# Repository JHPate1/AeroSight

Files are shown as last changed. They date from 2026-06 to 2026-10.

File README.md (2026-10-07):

# AeroSight
### An Open-Source, Low-Cost Retroreflective Schlieren Imaging System

## Overview
AeroSight is a high-fidelity Schlieren imaging device built to make advanced aerodynamic and thermodynamic visualization actually accessible. Professional-grade Schlieren setups, the kind NASA uses easily runs past $5,000. AeroSight delivers 1080p visualization for a fraction of that, using a modular optical design and open-source hardware. Swap lenses, swap beam splitters, tweak the software. The whole thing is built for people who want to experiment like real lab equipment.
Diagram
## How it looks inside
(Lost Media)
Guide:
Yellow-Enclosure
Blue-Lens Holder
Grey-Cam Holder
Orange-LED Holder
Red-BeamSplitter
## Why AeroSight?
* **Cheap where it counts:** Total build cost is about $514.
* **Modular:** Upgrade optics (lens, NPBS cube) as your needs change.
* **Flexible software:** Raw video, real-color rendering, custom gradient mapping, all the good stuff.

## Project Contents
```/PCB/``` PCB files
```3D ``` 3D Printed Files

## Bill of Materials (BOM)

| Category | Item | Quantity | Total |
| :--- | :--- | :--- | :--- |
| **Processing** | Waveshare ESP32-P4-WIFI6 Development Board | 1 | $24.99 |
| **Camera** | Arducam OV5647 5MP Camera (CS Mount) | 1 | $25.99 |
| **Camera Cable** | Raspberry Pi CSI Ribbon Cable | 1 | $4.99 |
| **Optics** | 25 mm 50:50 Beam Splitter Cube | 1 | $94.95 |
| **Optics** | Eisco Plano-Convex Lens (50mm) | 2 | $19.98 |
| **Optics** | Front Surface Mirror 5.5" x 8" | 1 | $12.98 |
| **Illumination** | 3 W 3535 High-Power White LED | 1 | $10.29 |
| **Cooling** | 30 mm 5 V Brushless Fan Kit | 1 | $9.99 |
| **Cooling** | 20x20x10 mm Aluminum Heatsink | 1 | $7.99 |
| **Thermal** | ARCTIC MX-7 Thermal Paste | 1 | $6.89 |
| **Mechanical** | Metric Screw/Nut/Washer Kit | 1 | $13.98 |
| **Electrical** | 28 AWG Silicone Wire | 1 | $10.82 |
| **Electrical** | SPST Rocker Switch Kit | 1 | $8.99 |
| **Audio** | 3 W 8 Ω Mini Speaker | 1 | $9.99 |
| **Assembly** | WEP 946D IV Mini Reflow Hot Plate | 1 | $28.79 |
| **PCBWay** | PCB Fabrication & 3D Printing | 1 | $163.50 |
| **Shipping/Tax**| Combined Est. Tax/Shipping/Tariffs | - | $58.88 |
| **---** | **GRAND TOTAL** | --- | **$514.00** |

---

## Customization & Notes
* **Modular optics:** The optical path is built to swap. Change the primary lens or NPBS cube depending on your field of view or light sensitivity needs.
* **Fabrication:** The 3D-printed enclosure eats a big chunk of the budget. If you have access to a printer in-house, you can knock about $126.50 off the total.

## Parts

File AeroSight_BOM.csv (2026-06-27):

Category | Item | Description | Qty | Unit Price | Line Total | Supplier | Link | Designator | Footprint
Processing | Waveshare ESP32-P4-WIFI6 | WiFi 6 dev board, MIPI-CSI support | 1 | $24.99 | $24.99 | Amazon | https://www.amazon.com/gp/product/B0FKH4KK7M
Camera | Arducam OV5647 5MP | 5MP CS-mount camera module | 1 | $25.99 | $25.99 | Amazon | https://www.amazon.com/gp/product/B012ETE75I
Camera | Raspberry Pi CSI Cable | 15-to-22 pin, 30 cm ribbon | 1 | $4.99 | $4.99 | Amazon | https://www.amazon.com/cart
Optics | NPBS Cube | 25 mm 50:50 non-polarizing, 400-700 nm | 1 | $94.95 | $94.95 | Labnique | https://labnique.com/products/25mm-beamsplitter-cube-non-polarizing-400-700-nm-broadband-50-50
Optics | Plano-Convex Lens | 50 mm dia, 50 mm focal length | 2 | $9.99 | $19.98 | Amazon | https://www.amazon.com/gp/product/B0FKHMTNPM
Optics | Front Surface Mirror | 5.5 in x 8 in, first-surface | 1 | $12.98 | $12.98 | Amazon | https://www.amazon.com/gp/product/B0BMJN2LVL
Illumination | White LED | 3W 3535, 6500-7000K | 1 | $10.29 | $10.29 | Amazon | https://www.amazon.com/gp/product/B0CL8XPX21
Cooling | 30 mm Fan | 5V brushless, sleeve bearing | 1 | $9.99 | $9.99 | Amazon | https://www.amazon.com/gp/product/B0792BW2VH
Cooling | Aluminum Heatsink | 20x20x10 mm, passive | 1 | $7.99 | $7.99 | Amazon | https://www.amazon.com/gp/product/B0FPCVP3QZ
Thermal | ARCTIC MX-7 | Thermal paste, 4g tube | 1 | $6.89 | $6.89 | Amazon | https://www.amazon.com/gp/product/B0FT2TSY47
Mechanical | Hardware Kit | M3-M6 screws, nuts, washers | 1 | $13.98 | $13.98 | Amazon | https://www.amazon.com/gp/product/B0BN297MP5
Electrical | Silicone Wire | 28 AWG, multi-color set | 1 | $10.82 | $10.82 | Amazon | https://www.amazon.com/gp/product/B07HGT77R5
Electrical | Rocker Switch | SPST, panel mount kit | 1 | $8.99 | $8.99 | Amazon | https://www.amazon.com/gp/product/B0DLBD4X2B
Audio | Mini Speaker | 3W, 8 ohm | 1 | $9.99 | $9.99 | Amazon | https://www.amazon.com/gp/product/B0B4D1BN4F
Assembly | Mini Reflow Hot Plate | WEP 946D IV, preheater | 1 | $28.79 | $28.79 | Amazon | https://www.amazon.com/gp/product/B0FDWNMC71
PCB Passives | Ceramic Capacitor | 10 uF, 0504 (1310 metric) | 3 | TBD | TBD | DigiKey/Mouser |  | C1-C3 | C_0504_1310Metric
PCB Passives | Ceramic Capacitor | 22 uF, 0504 (1310 metric) | 1 | TBD | TBD | DigiKey/Mouser |  | C4 | C_0504_1310Metric
PCB Passives | LED | 0805 (2012 metric), status indicator | 2 | TBD | TBD | DigiKey/Mouser |  | D1-D2 | LED_0805_2012Metric
PCB Passives | Schottky Diode | SS14, SMA package | 2 | TBD | TBD | DigiKey/Mouser |  | D3-D4 | D_SMA
PCB Passives | Inductor | 22 uH, 0805 (2012 metric) | 1 | TBD | TBD | DigiKey/Mouser |  | L1 | L_0805_2012Metric
PCB Passives | Inductor | 68 uH, 0805 (2012 metric) | 1 | TBD | TBD | DigiKey/Mouser |  | L2 | L_0805_2012Metric
PCB Passives | Resistor | 5.1 kOhm, 0603 (1608 metric) | 1 | TBD | TBD | DigiKey/Mouser |  | R1 | R_0603_1608Metric
PCB Passives | Resistor | 1.6 kOhm, 0603 (1608 metric) | 1 | TBD | TBD | DigiKey/Mouser |  | R2 | R_0603_1608Metric
PCB Passives | Resistor | 1 kOhm, 0603 (1608 metric) | 2 | TBD | TBD | DigiKey/Mouser |  | R3-R4 | R_0603_1608Metric
PCB Passives | Resistor | 75 kOhm, 0603 (1608 metric) | 1 | TBD | TBD | DigiKey/Mouser |  | R5 | R_0603_1608Metric
PCB Passives | Resistor | 10 kOhm, 0603 (1608 metric) | 1 | TBD | TBD | DigiKey/Mouser |  | R6 | R_0603_1608Metric
PCB Passives | Resistor | TBD value, 0603 (1608 metric) | 1 | TBD | TBD | DigiKey/Mouser |  | R7 | R_0603_1608Metric
PCB ICs | Li-Ion Charger | TP4057, TSOT-23-6 | 1 | TBD | TBD | LCSC/DigiKey |  | U1 | TSOT-23-6
PCB ICs | Boost Converter | MT3608, SOT-23-6 | 1 | TBD | TBD | LCSC/DigiKey |  | U2 | SOT-23-6
PCB ICs | LED Driver | AL8860MP, MSOP-8-1EP | 1 | TBD | TBD | DigiKey/Mouser |  | U3 | MSOP-8-1EP_3x3mm_P0.65mm_EP1.5x1.8mm
PCB Connectors | Pin Socket | 1x20, 2.54 mm pitch, vertical | 2 | TBD | TBD | DigiKey/Mouser |  | J1-J2 | PinSocket_1x20_P2.54mm_Vertical
PCB Connectors | Pin Header | 1x02, 2.54 mm pitch, vertical | 2 | TBD | TBD | DigiKey/Mouser |  | J3-J4 | PinHeader_1x02_P2.54mm_Vertical
PCB Connectors | Pin Socket | 1x02, 2.00 mm pitch, vertical | 1 | TBD | TBD | DigiKey/Mouser |  | J5 | PinSocket_1x02_P2.00mm_Vertical
PCB Connectors | Pin Socket | 1x02, 2.54 mm pitch, vertical | 3 | TBD | TBD | DigiKey/Mouser |  | J6-J8 | PinSocket_1x02_P2.54mm_Vertical
PCB Connectors | USB-C Receptacle | Amphenol 12401948E412A, USB 2.0 | 1 | TBD | TBD | DigiKey/Mouser |  | J9 | USB_C_Receptacle_Amphenol_12401948E412A
Fabrication | PCB | 2-layer, custom design | 1 | $37.00 | $37.00 | PCBWay
Fabrication | 3D Printing | Enclosure parts, SLA/FDM | 1 | $126.50 | $126.50 | PCBWay
Shipping | Amazon Shipping + Tax | Combined estimate | 1 | $31.40 | $31.40 | Amazon
Shipping | Labnique Shipping + Tax | Combined estimate | 1 | $9.99 | $9.99 | Labnique
Shipping | PCBWay Taxes/Tariffs | Estimated import duties | 1 | $17.50 | $17.50 | PCBWay
SUBTOTAL | Mechanical / Off-the-Shelf |  |  |  | $291.61
SUBTOTAL | PCB Components |  |  |  | TBD
SUBTOTAL | Fabrication & Shipping |  |  |  | $222.39
GRAND TOTAL |  |  |  |  | $514.00 + PCB

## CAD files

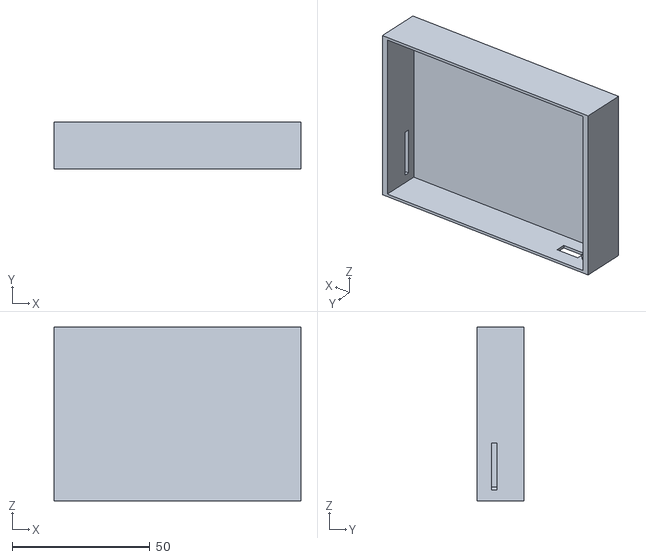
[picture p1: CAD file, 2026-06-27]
3D/Main-Enclosure.stl
89.5 x 17.0 x 63.0

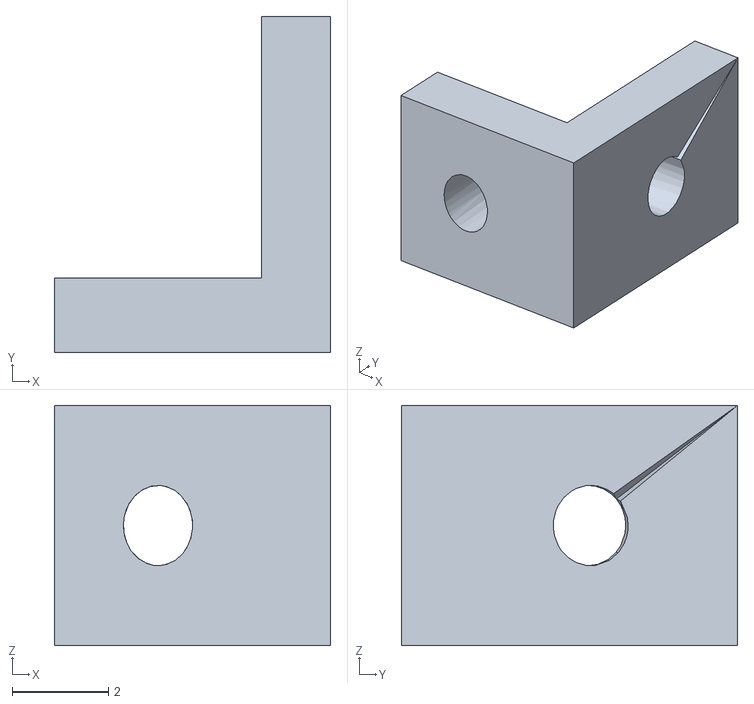
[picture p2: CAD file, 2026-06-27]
3D/Large-Bracker.stl
5.75 x 7.00 x 5.00

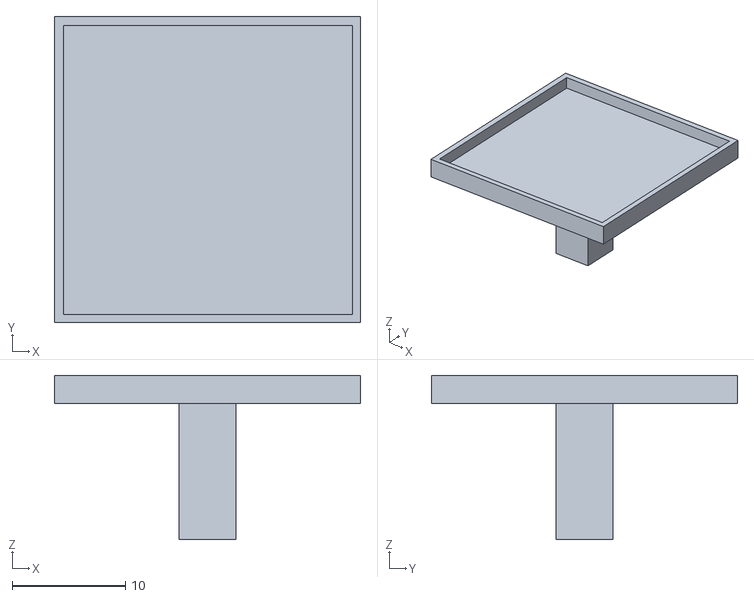
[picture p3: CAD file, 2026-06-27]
3D/NPBS-Holder.stl
27.0 x 27.0 x 14.5

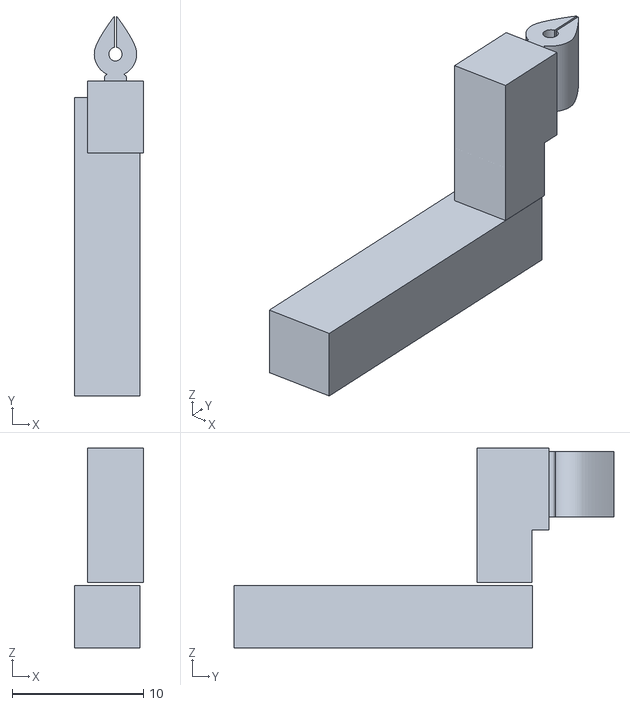
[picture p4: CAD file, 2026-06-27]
3D/RailArm.stl
5.25 x 29.0 x 15.3

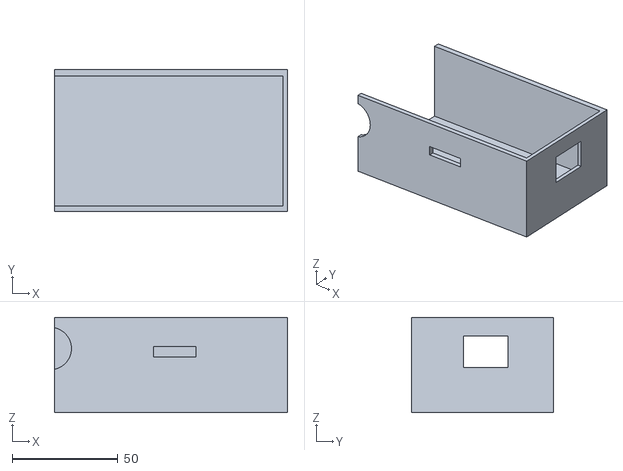
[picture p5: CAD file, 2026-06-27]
3D/Section1.stl
110.0 x 67.0 x 45.0

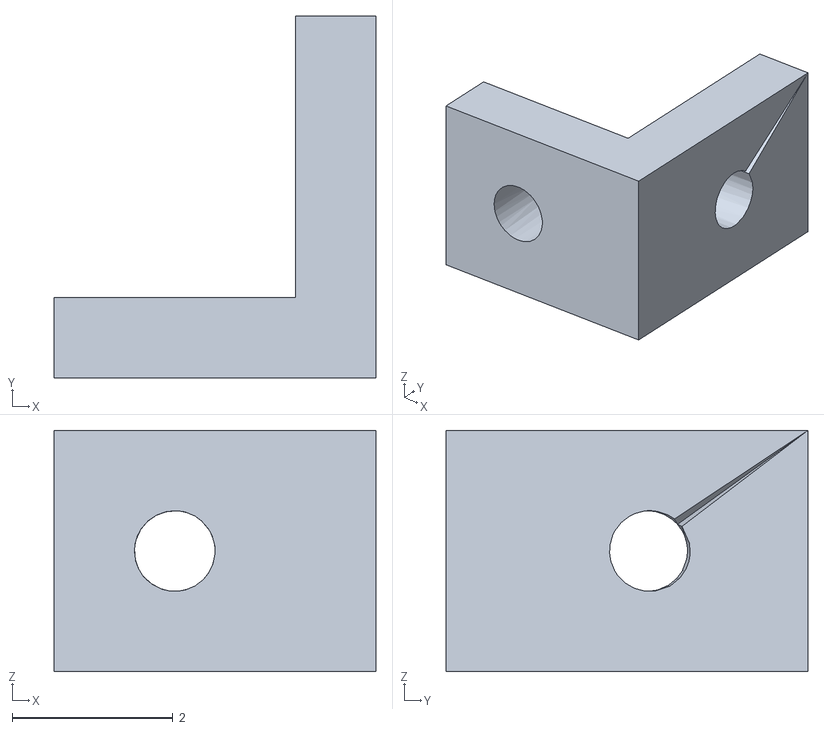
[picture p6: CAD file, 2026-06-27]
3D/Small-Bracket.stl
4.00 x 4.50 x 3.00

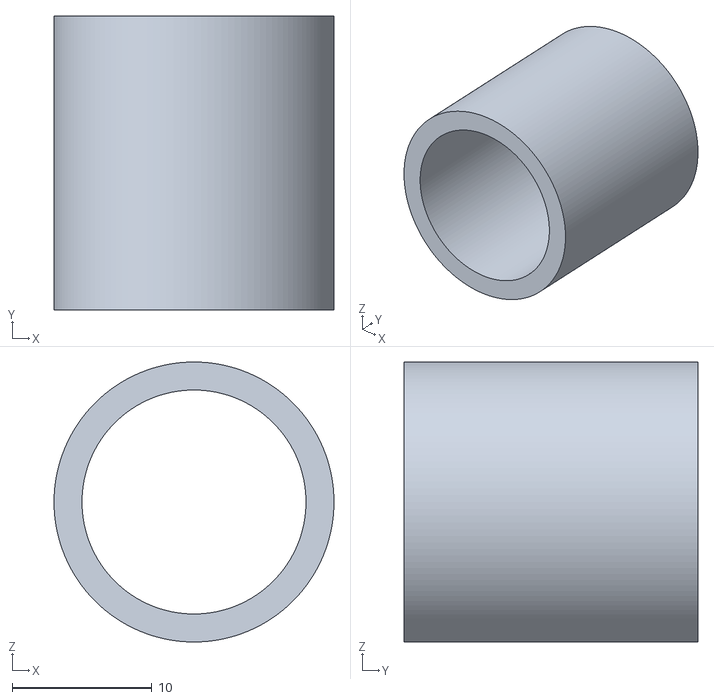
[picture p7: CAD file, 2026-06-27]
3D/Muzzle.stl
20.0 x 21.0 x 20.0

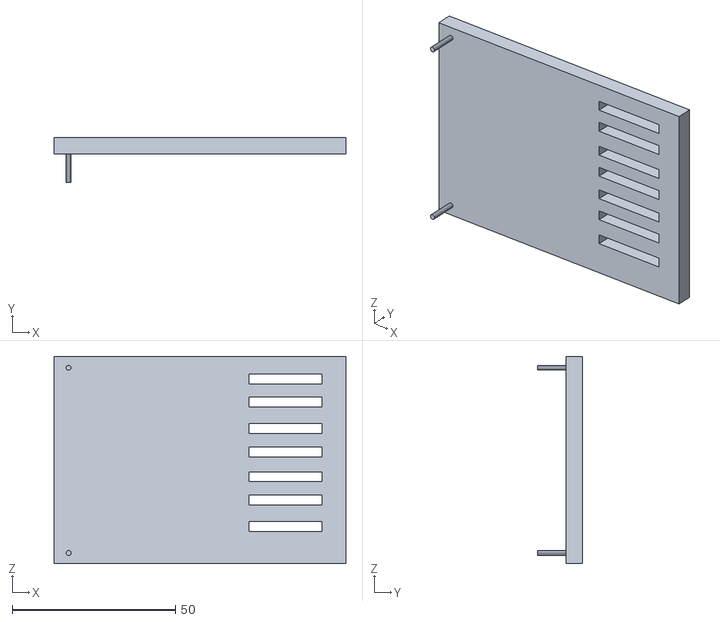
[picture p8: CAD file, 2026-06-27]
3D/Face-Plate.stl
89.5 x 13.8 x 63.5

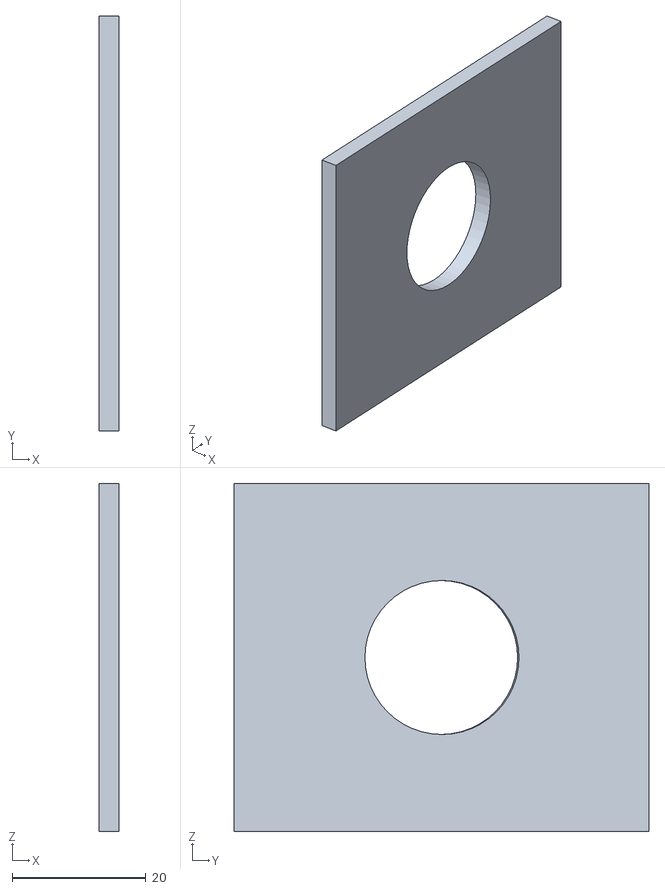
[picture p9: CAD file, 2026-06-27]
3D/CameraHolder.stl
2.99 x 62.0 x 52.0

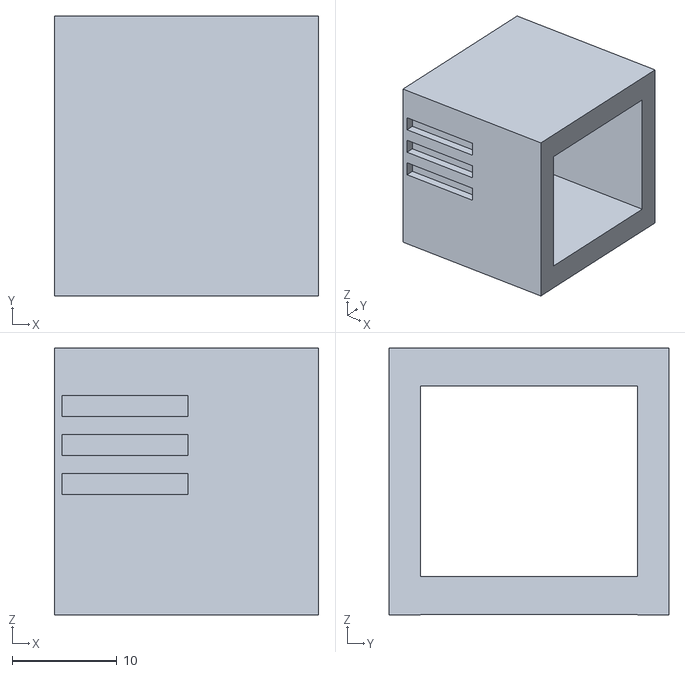
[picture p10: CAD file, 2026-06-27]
3D/LEDCasing.stl
25.2 x 26.8 x 25.5

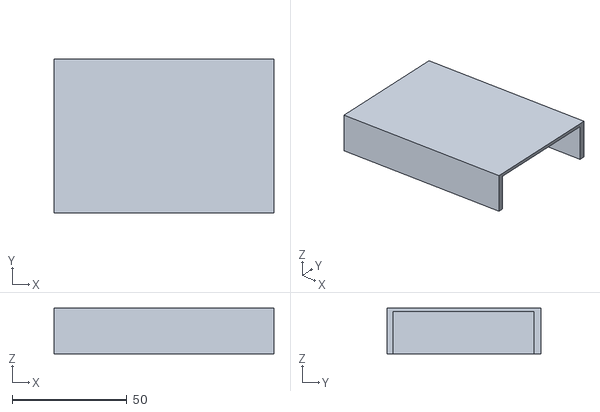
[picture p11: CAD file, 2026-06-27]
3D/Top-Section2.stl
95.7 x 67.2 x 20.0

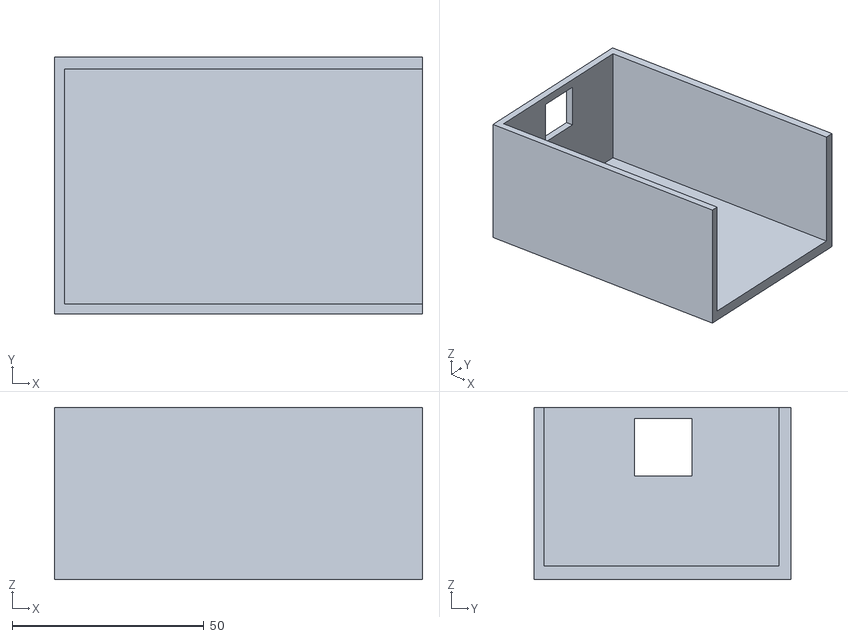
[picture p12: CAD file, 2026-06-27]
3D/Section2.stl
96.0 x 67.0 x 45.0

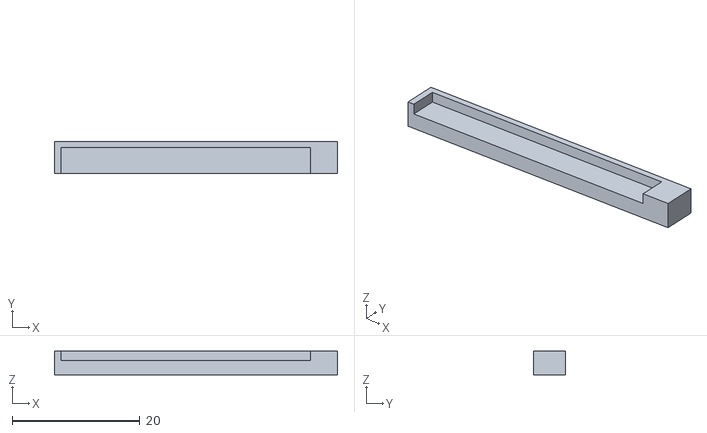
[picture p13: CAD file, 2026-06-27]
3D/Rail.stl
44.2 x 5.00 x 3.75

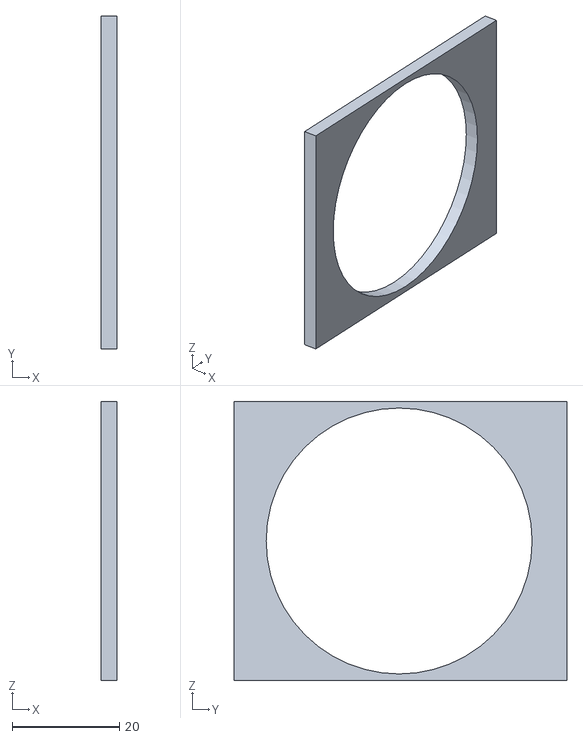
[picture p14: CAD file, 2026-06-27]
3D/Lens-Holder.stl
2.99 x 62.0 x 52.0

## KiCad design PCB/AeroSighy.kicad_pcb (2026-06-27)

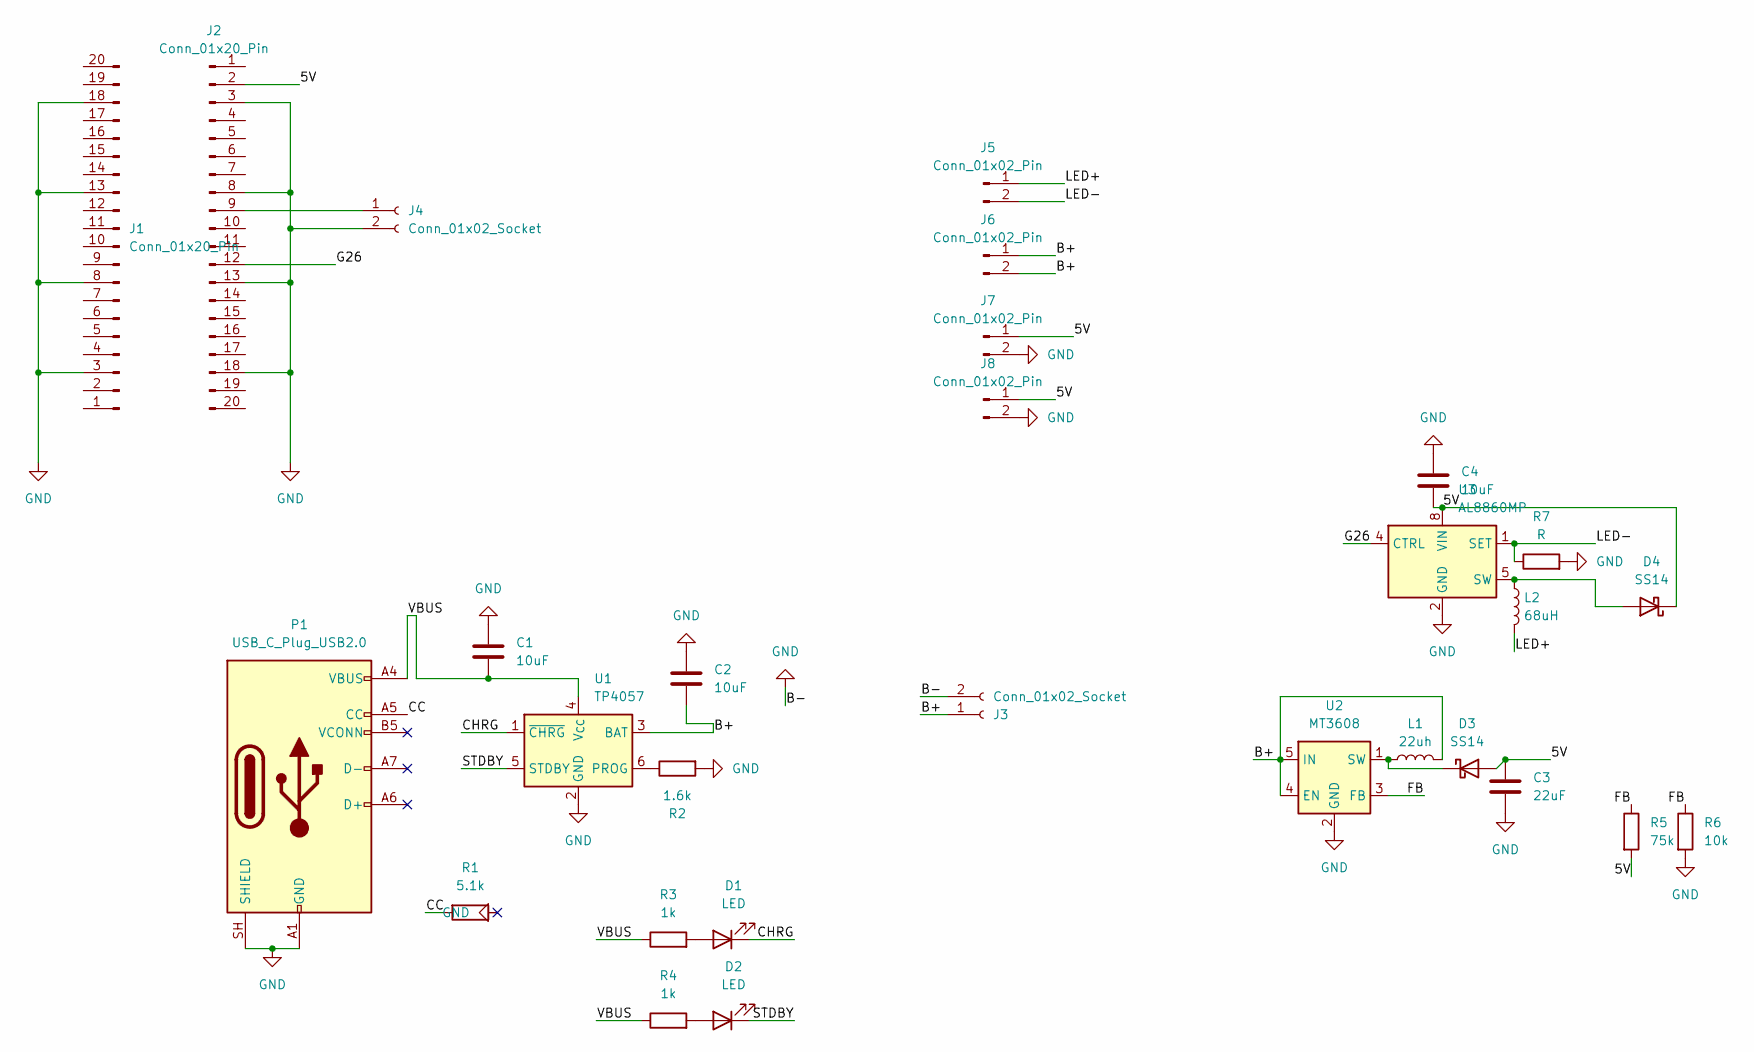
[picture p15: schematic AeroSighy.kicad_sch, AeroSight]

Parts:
C1, C2, C4: 10uF; C_0504_1310Metric
C3: 22uF; C_0504_1310Metric
D1, D2: LED; LED_0805_2012Metric
D3, D4: SS14; D_SMA
J1, J2: Conn_01x20_Pin; PinSocket_1x20_P2.54mm_Vertical
J3, J4: Conn_01x02_Socket; PinHeader_1x02_P2.54mm_Vertical
J5: Conn_01x02_Pin; PinSocket_1x02_P2.00mm_Vertical
J6, J7, J8: Conn_01x02_Pin; PinSocket_1x02_P2.54mm_Vertical
L1: 22uh; L_0805_2012Metric
L2: 68uH; L_0805_2012Metric
P1: USB_C_Plug_USB2.0; USB_C_Receptacle_Amphenol_12401948E412A
R1: 5.1k; R_0603_1608Metric
R2: 1.6k; R_0603_1608Metric
R3, R4: 1k; R_0603_1608Metric
R5: 75k; R_0603_1608Metric
R6: 10k; R_0603_1608Metric
R7: R; R_0603_1608Metric
U1: TP4057; TSOT-23-6
U2: MT3608; SOT-23-6
U3: AL8860MP; MSOP-8-1EP_3x3mm_P0.65mm_EP1.5x1.8mm

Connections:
/5V: C3.1, C4.2, D3.2 (A), D4.1 (K), J2.2, J7.1, J8.1, R5.2, U3.8 (VIN)
/B+: C2.2, J3.1, J6.1, J6.2, L1.2, U1.3 (BAT), U2.4 (EN), U2.5 (IN)
/CC: P1.A5 (CC), R1.2
/CHRG: D1.1 (K), U1.1 (~CHRG)
/FB: R5.1, R6.1, U2.3 (FB)
/G26: J2.12, U3.4 (CTRL)
/LED+: J5.1, L2.2
/LED-: J5.2, R7.1, U3.1 (SET)
/STDBY: D2.1 (K), U1.5 (STDBY)
/VBUS: C1.2, P1.A4 (VBUS), P1.A9 (VBUS), P1.B4 (VBUS), P1.B9 (VBUS), R3.1, R4.1, U1.4 (V_{CC})
GND: C1.1, C2.1, C3.2, C4.1, J1.3, J1.8, J1.13, J1.18, J2.3, J2.8, J2.13, J2.18, J3.2, J4.2, J7.2, J8.2, P1.A1 (GND), P1.A12 (GND), P1.B1 (GND), P1.B12 (GND), P1.SH (SHIELD), R1.1, R2.2, R6.2, R7.2, U1.2 (GND), U2.2 (GND), U3.2 (GND), U3.3 (GND), U3.9 (GND)
unnamed: D1.2 (A), R3.2
unnamed: D2.2 (A), R4.2
unnamed: D3.1 (K), L1.1, U2.1 (SW)
unnamed: D4.2 (A), L2.1, U3.5 (SW), U3.6 (SW)
unnamed: J2.9, J4.1
unnamed: R2.1, U1.6 (PROG)

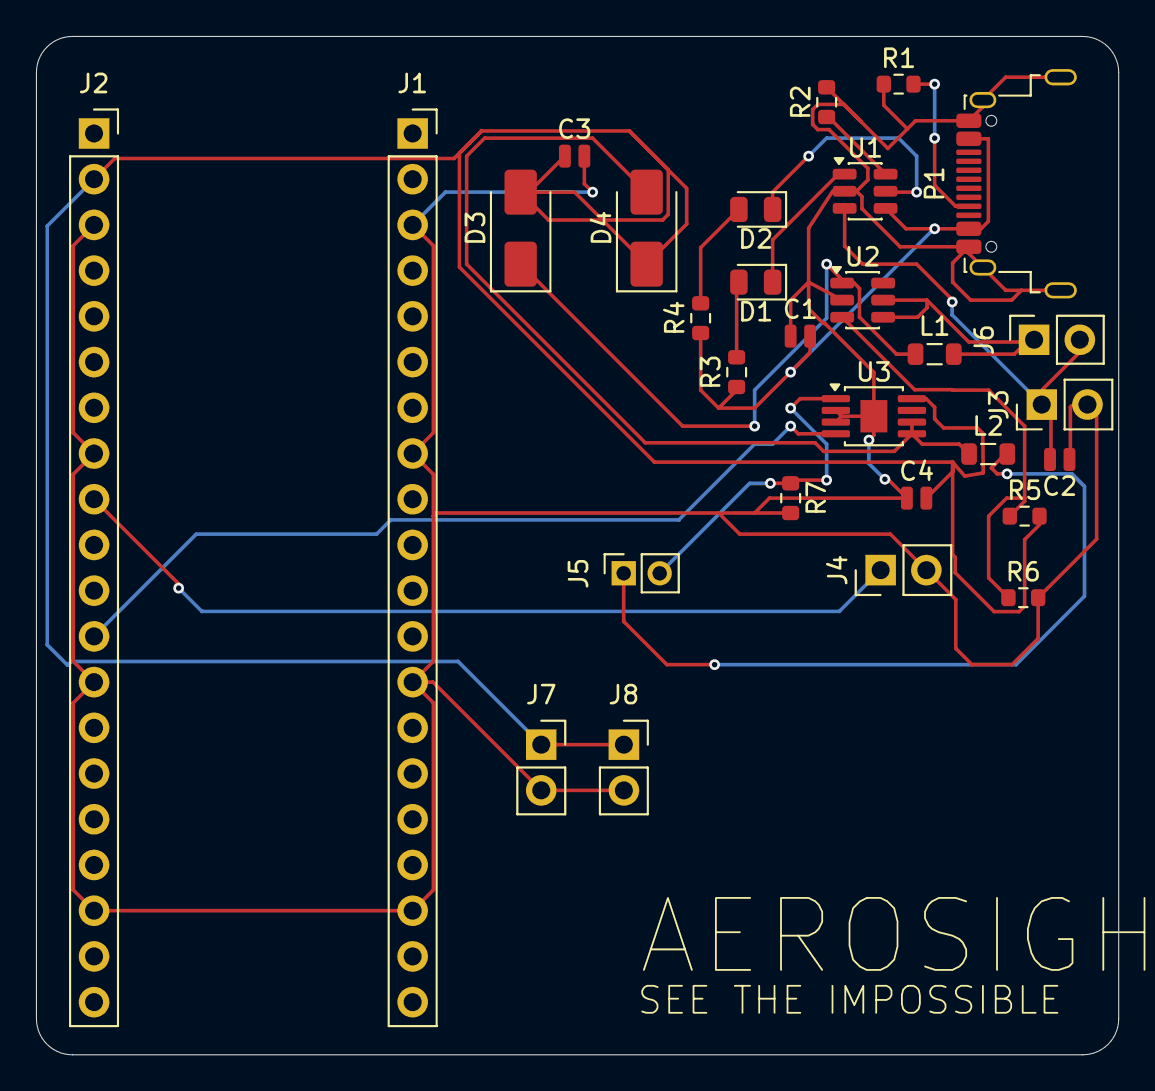
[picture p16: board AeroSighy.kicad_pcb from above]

Board: 2 copper layers, 60.1 x 56.6 mm, 29 parts (0 on the bottom side), 17 nets.

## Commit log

2026-06-27 Revise README for AeroSight project details
    Updated the README to provide a detailed overview of the AeroSight project, including its features, project contents, bill of materials, and customization notes.
2026-06-28 Add internal view section to README
    Added a section on the internal appearance of the device with an image.
2026-07-01 Create BASE-CODE.C
    Code for the ESP32-P4
